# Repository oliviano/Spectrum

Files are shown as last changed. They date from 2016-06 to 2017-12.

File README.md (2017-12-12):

# SPECTRUM

## Arduino Pro Mini LED PWM Controller:

Basic Function:

 * Reads a potentiometre ( aka cheap rotary encoder )
 * Map potentiometre reading to a Hue
 * Signal filtering & Logic
 * Converts Hue, Sat, Brightness to RGB
 * Make Beautiful & playfull light for Sydney VIVId 2016

Pre Requisites:
  * Library Average [link](https://github.com/MajenkoLibraries/Average)

Deployed for Sydney Vivid 2016 artwork "Spectrum"

To Do:
 * Add Average library file or link

 * IP67/68 Connectors -> alibaba led 4pin connectors
 * Calibration TrimPot on board + code + new board
 * Smaller Gauge Cable !!!!!!!
 * Beautify Hue Variation
 * WS281'ing the setup
 * Install a webcam so I can see it from afar.
 * Idle Mode ?

And here's some code!

```CPP
$(function(){
  $('div').html('I am a div.');
});
```

Check the work out  [on Vivid Website](http://www.vividsydney.com/event/light/spectrum) it's the render view, hopefully Vivid changes it sometime.

Shot to all the ressources online, great mind sharing amazing code.

### Stuff used to make this:

 * [markdown editor](https://jbt.github.io/markdown-editor/) for Markdown parsing
 * [hallertau Statesman] (http://www.hallertau.co.nz/craft-beer/#number-2) for making a fine beverage

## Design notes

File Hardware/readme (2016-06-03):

- Board layout created with eagle 6.9.74 for OSx 
- Part Library from Sparkfun & Adafruits

- BOM -
Potentiometres - 10K Linear
N-Channel Mosfet - Low Gate Voltage ( micro controller friendly ) 10A - 60V Rated
10K PullDown Resistor for Gate of Mosfet
--
Connectors
Box
12V Power supplier
Cables

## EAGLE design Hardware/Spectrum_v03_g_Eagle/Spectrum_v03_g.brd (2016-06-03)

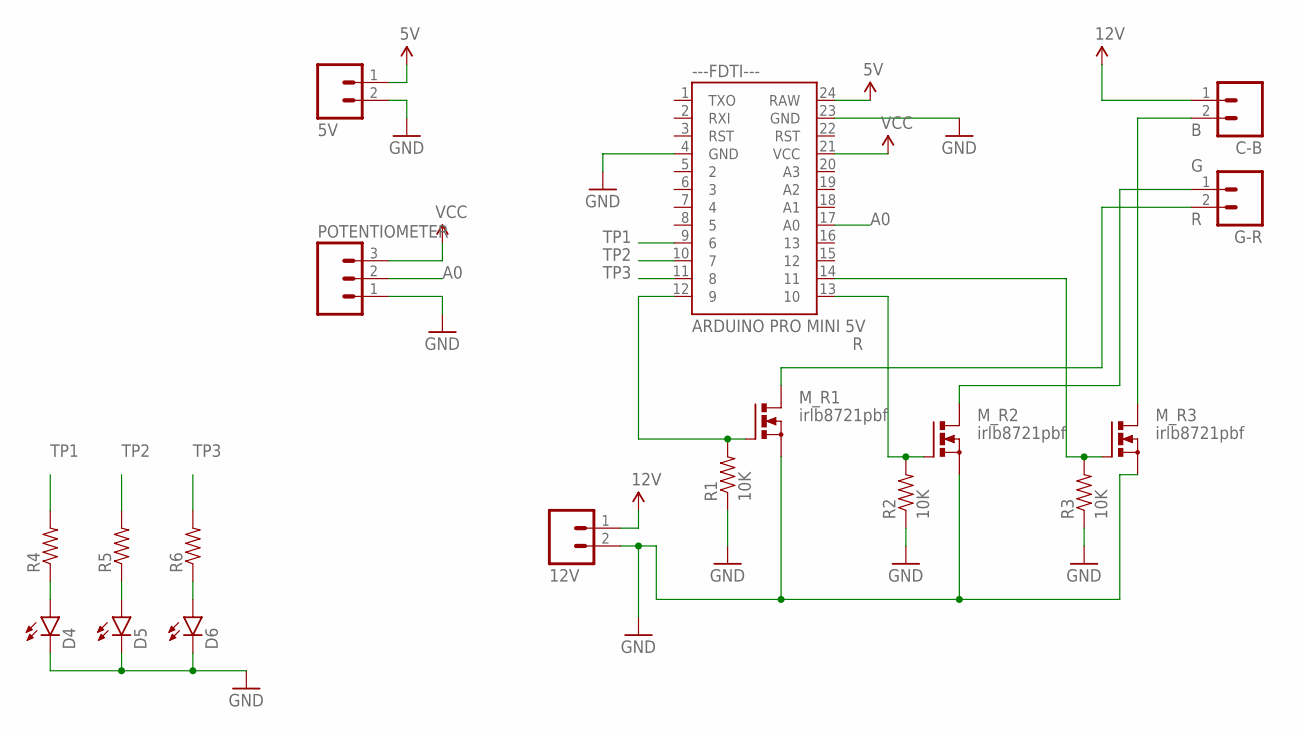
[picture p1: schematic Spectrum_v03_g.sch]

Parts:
5V, 12V: M025MM; SCREWTERMINAL-5MM-2
---FDTI---: ARDUINO PRO MINI 5V; ARDUINO_MINI
C-B: M025MM; SCREWTERMINAL-5MM-2
D4, D5, D6: LED3MM
G-R: M025MM; SCREWTERMINAL-5MM-2
M_R1, M_R2, M_R3: irlb8721pbf; TO220BV
POTENTIOMETER: M03-SCREW-5MM; SCREWTERMINAL-5MM-3
R1, R2, R3: 10K; AXIAL-0.4
R4, R5, R6: RESISTOREZ; AXIAL-0.3EZ

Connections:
5V: 5V.1, ---FDTI---.24 (RAW)
12V: 12V.1, C-B.1
A0: ---FDTI---.17 (A0), POTENTIOMETER.2
B: C-B.2, M_R3.D
G: G-R.1, M_R2.D
GND: 5V.2, 12V.2, ---FDTI---.4 (GND), ---FDTI---.23 (GND), D4.K (C), D5.K (C), D6.K (C), M_R1.S, M_R2.S, M_R3.S, POTENTIOMETER.1, R1.P$1 (1), R2.P$1 (1), R3.P$1 (1)
unnamed: ---FDTI---.12 (9), M_R1.G, R1.P$2 (2)
unnamed: ---FDTI---.13 (10), M_R2.G, R2.P$2 (2)
unnamed: ---FDTI---.14 (11), M_R3.G, R3.P$2 (2)
unnamed: D4.A, R4.P$1 (1)
unnamed: D5.A, R5.P$1 (1)
unnamed: D6.A, R6.P$1 (1)
R: G-R.2, M_R1.D
TP1: ---FDTI---.9 (6), R4.P$2 (2)
TP2: ---FDTI---.10 (7), R5.P$2 (2)
TP3: ---FDTI---.11 (8), R6.P$2 (2)
VCC: ---FDTI---.21 (VCC), POTENTIOMETER.3

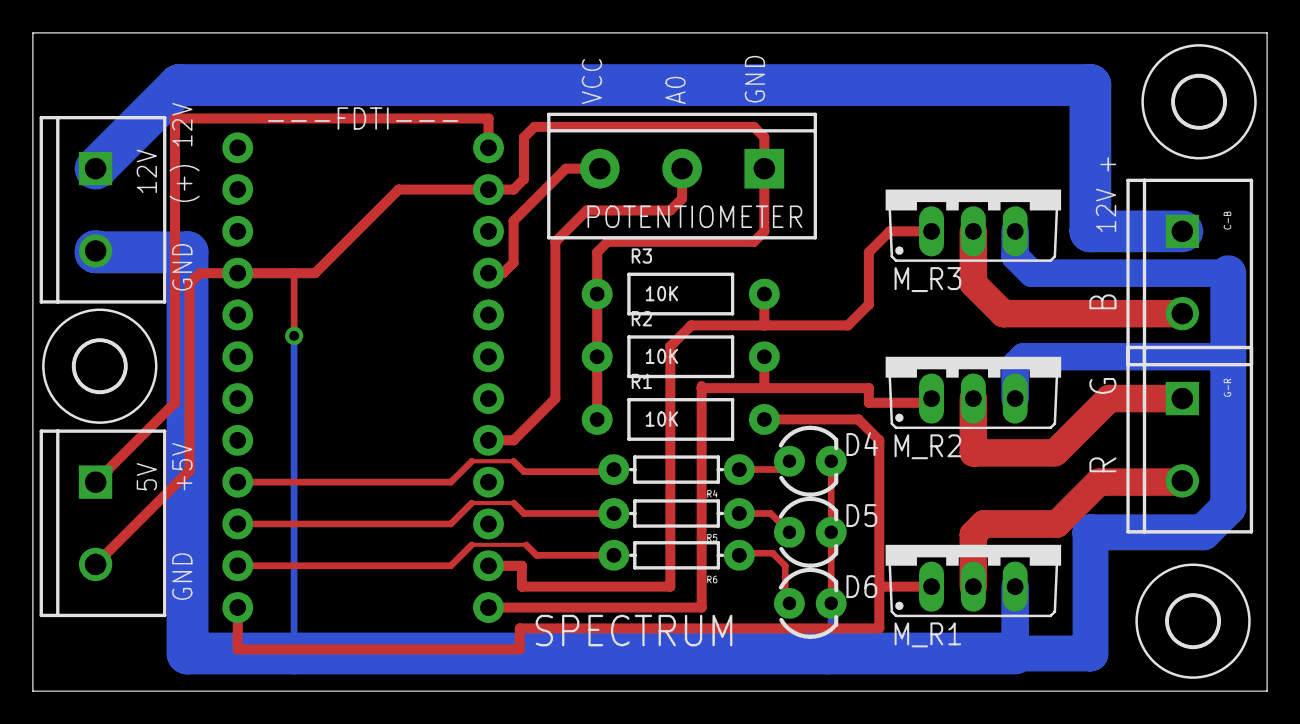
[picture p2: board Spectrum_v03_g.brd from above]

Board: 2 copper layers, 75.0 x 40.0 mm, 21 parts (0 on the bottom side), 17 nets.

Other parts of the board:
U$2, U$3, U$4: 3,0

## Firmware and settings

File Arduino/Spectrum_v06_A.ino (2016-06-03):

#include <Average.h>
// VIVID Test Code for Spectrum v04 May 22th 2016 _ Olivier Jean
// HSV to RGB code_ 
// Circuit with N-Mofset and pull-down resistor
// Arduino Mini Version _06 - PCB vG


// just a tree val media filter. still some aberation on the color spectrum.

Average<int> ave(12); // use to be flaot - int less math ? / maybe i float all those ?
// ************* ************* ************* *************
// pot travel is 300º for 1023 value change. 1º = 3.41
// travel we want is 40 º /  -20 ---- +20
// 20 º = 68.2 |  150º = 511.5
// midle point is  511.5
// 443.3 -- 511.5 -- 597.7 is the sensor value we want
// ************* ************* ************* *************

// ************* ********** DEBUG ********* ************* //

int DEBUG = 0; // Debug enable = 1 , switch to 0 to desiable debug. ( debug slows the mini quite a lot )

// ************* ***** USER VARIABLES ***** ************* //

int potMin = 0  ;   // Value Mapped Start angle  aka (( 1023 / 300º ) * 150º ) - ((1023 / 300º)* 20º )
int potMax = 1023;   // Value Mapped End angle  aka (( 1023 / 300º ) * 150º ) + ((1023 / 300º)* 20º )
int hueMin = 0;     // Start Hue 0 for pit on the right ( looking from project box ) - invert aka 325 for other side
int hueMax = 360;   // End Hue either 325

// ************* ***** XXXX XXXXXXXXX ***** ************* //

// Pin declarations:
int LEDRed = 9;
int LEDGreen = 10;
int LEDBlue = 11;

int sensorPin = A0;
int newest = 0;
int recent = 0;
int oldest = 0;

// Variables
int valRaw; //Raw Value
int ValCons; // Constrain Value to potMin / potMax
int valMap; // Mapped Value to ( hueMin/hueMax )
int valSmooth; // Smooth'ed Val.

//  Average Library - Average Bucket Size  < int > can be float //
//Average<float> ave(10);

// Init RGB Array
int rgb[3];
// ************* ***** **** SETUP *** ****** ************* //
void setup() {

  // median filter start
  oldest = analogRead(A0);
  recent = oldest;
  newest = recent;

  // Pin Declaration
  pinMode(LEDRed, OUTPUT);
  pinMode(LEDGreen, OUTPUT);
  pinMode(LEDBlue, OUTPUT);

  if (DEBUG == 1 ) {
    Serial.begin(9600); // Set up the serial output
  }

  if (DEBUG == 0 ) { // Boot Up sequence R 4sec - G 4sec - B 4sec //
    analogWrite(LEDRed, 255);
    analogWrite(LEDBlue, 0);
    analogWrite(LEDGreen, 0);
    delay(4000);
    analogWrite(LEDRed, 0);
    analogWrite(LEDGreen, 255);
    analogWrite(LEDBlue, 0);
    delay(4000);
    analogWrite(LEDRed, 0);
    analogWrite(LEDGreen, 0);
    analogWrite(LEDBlue, 255);
    delay(4000);
    analogWrite(LEDRed, 255);
    analogWrite(LEDBlue, 0);
    analogWrite(LEDGreen, 0);
    delay(500);
    analogWrite(LEDRed, 0);
    analogWrite(LEDGreen, 255);
    analogWrite(LEDBlue, 0);
    delay(500);
    analogWrite(LEDRed, 0);
    analogWrite(LEDGreen, 0);
    analogWrite(LEDBlue, 255);
    delay(500);
  }
}

void loop() {

  valRaw = analogRead(sensorPin); // Read Pot Value

  ValCons = constrain (valRaw, potMin, potMax); // limits range of sensor values to between potMin(443) and potMax(597)

  valMap = map(ValCons, potMin, potMax, hueMin, hueMax); // map the ValCons'train to hue

  ave.push(valMap); // Add new value to the average bucket

  //oldest = recent;
  //recent = newest;
  //newest = valMap;

  //int median = median_of_3( oldest, recent, newest );

  valSmooth = ave.mean(); // Average Smooth

  // DO HSV to RGB

  hsi2rgb(valSmooth, 1, 1, rgb);

  //hsi2rgb(median, 1, 1, rgb);

  // ------------
  // Display to LED
  analogWrite(LEDRed, rgb[0]);
  analogWrite(LEDBlue, rgb[1]);
  analogWrite(LEDGreen, rgb[2]);
  // ------------

  // Debug Function Serial Write //
  if (DEBUG) {
    Serial.print(" raw : ");
    Serial.print(valRaw);
    //Serial.print(" Constrain : ");
    // Serial.print(ValCons);
    Serial.print(" Hue Normal : ");
    Serial.print(valMap);
    Serial.print(" Average : ");
    Serial.print(valSmooth);
    Serial.print("--   OUT R: ");
    Serial.print(rgb[0]);
    Serial.print(" G: ");
    Serial.print(rgb[1]);
    Serial.print(" B: ");
    Serial.print(rgb[2]);
    Serial.println("  ");
  }




}

//  Median Filter Function // Low Pass Filter on 3 Sample ~
/*
  median_filter.ino
  2014-03-25: started by David Cary
  http://arduino.stackexchange.com/questions/246/are-there-any-signal-smoothing-libraries-for-arduino
*/

int median_of_3( int a, int b, int c ) {
  int the_max = max( max( a, b ), c );
  int the_min = min( min( a, b ), c );
  // unnecessarily clever code
  int the_median = the_max ^ the_min ^ a ^ b ^ c;
  return ( the_median );
}


// FUNCTION STOLEN FROM
// http://blog.saikoled.com/post/43693602826/why-every-led-light-should-be-using-hsi-colorspace on 10/27/14
// Function example takes H, S, I, and a pointer to the
// returned RGB colorspace converted vector. It should
// be initialized with:
//
// int rgb[3];
//
// in the calling function. After calling hsi2rgb
// the vector rgb will contain red, green, and blue
// calculated values.
// Example to call Value:
// int rgb[3];
// hsi2rgb(90.0, 1, 1, rgb);
// H hue / Saturation / Intensity
// strip.setPixelColor(1,strip.Color(rgb[0],rgb[1],rgb[2]));

void hsi2rgb(float H, float S, float I, int* rgb) {
  int r, g, b;
  H = fmod(H, 360); // cycle H around to 0-360 degrees
  H = 3.14159 * H / (float)180; // Convert to radians.
  S = S > 0 ? (S < 1 ? S : 1) : 0; // clamp S and I to interval [0,1]
  I = I > 0 ? (I < 1 ? I : 1) : 0;

  // Math! Thanks in part to Kyle Miller. Your awesome Kyle !
  if (H < 2.09439) {
    r = 255 * I / 3 * (1 + S * cos(H) / cos(1.047196667 - H));
    g = 255 * I / 3 * (1 + S * (1 - cos(H) / cos(1.047196667 - H)));
    b = 255 * I / 3 * (1 - S);
  } else if (H < 4.188787) {
    H = H - 2.09439;
    g = 255 * I / 3 * (1 + S * cos(H) / cos(1.047196667 - H));
    b = 255 * I / 3 * (1 + S * (1 - cos(H) / cos(1.047196667 - H)));
    r = 255 * I / 3 * (1 - S);
  } else {
    H = H - 4.188787;
    b = 255 * I / 3 * (1 + S * cos(H) / cos(1.047196667 - H));
    r = 255 * I / 3 * (1 + S * (1 - cos(H) / cos(1.047196667 - H)));
    g = 255 * I / 3 * (1 - S);
  }
  // Returns / Fill the array with the newly calculated values.
  rgb[0] = r;
  rgb[1] = g;
  rgb[2] = b;
}

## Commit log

2016-06-03 Initial commit - Arduino Code
2016-06-03 Initial Commit - Eagle Files
    [Spectrum_v03_g.GBL, Spectrum_v03_g.GBO, Spectrum_v03_g.GBS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]
2016-06-03 Update Readme
    Added BOM

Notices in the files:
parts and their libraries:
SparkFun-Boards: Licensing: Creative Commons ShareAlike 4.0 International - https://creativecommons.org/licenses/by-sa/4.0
